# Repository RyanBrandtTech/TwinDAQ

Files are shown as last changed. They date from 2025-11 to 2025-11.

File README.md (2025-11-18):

# TwinDAQ
* An STM32-based two-channel analog I/O data acquisition system and development board

## Features
* Two analog inputs accessible with SMA connectors
* Two analog outputs accessible with SMA connectors
* Eight digital GPIO accessible via 0.1" female pin headers
* Two RGB LEDs for visual debugging
* Connector for SWD interfacing
* Connector for UART interfacing
* Micro-USB for 5V power and USB2.0 communications

### Dimensions and Images
40 mm x 60 mm
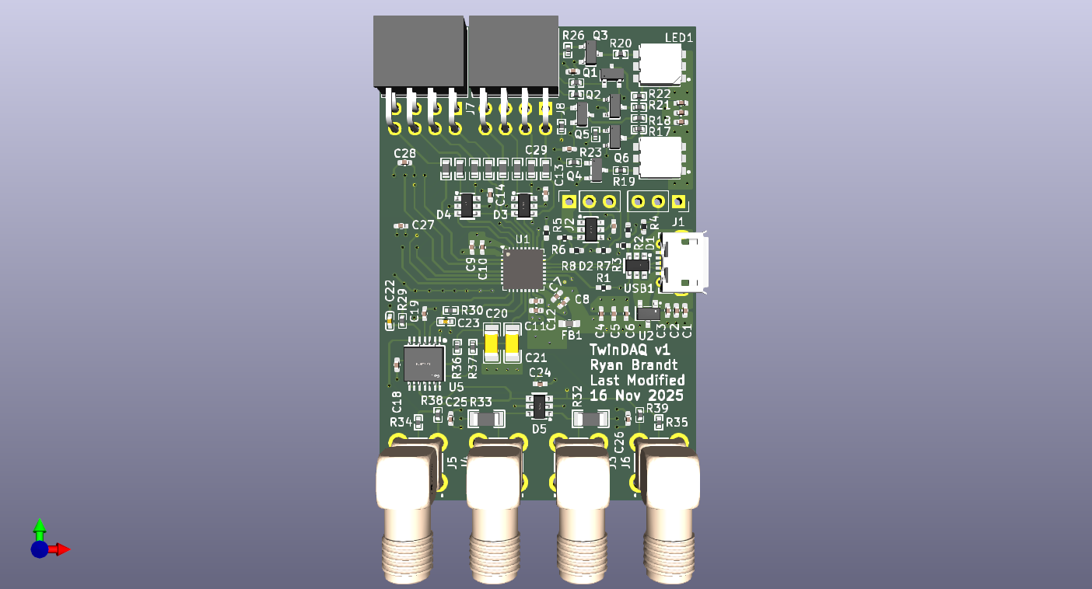
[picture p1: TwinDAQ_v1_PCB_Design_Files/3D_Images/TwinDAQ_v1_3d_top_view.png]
Top View of the TwinDAQv1 PCBA Top View

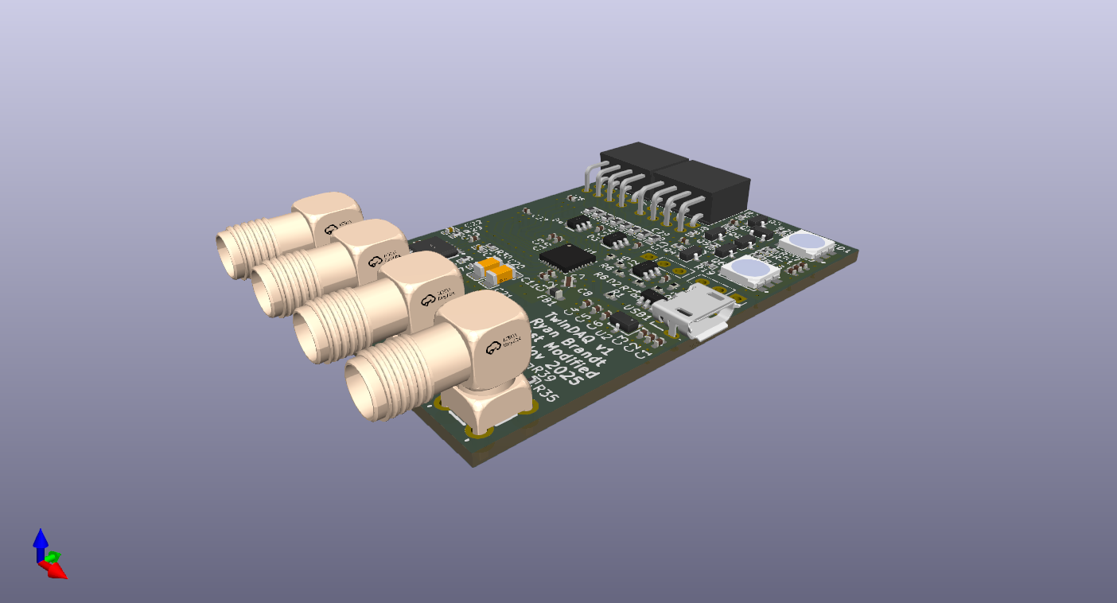
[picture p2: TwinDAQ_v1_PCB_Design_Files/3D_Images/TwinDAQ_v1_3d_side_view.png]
Front Side View of the TwinDAQv1 PCBA Front Side View

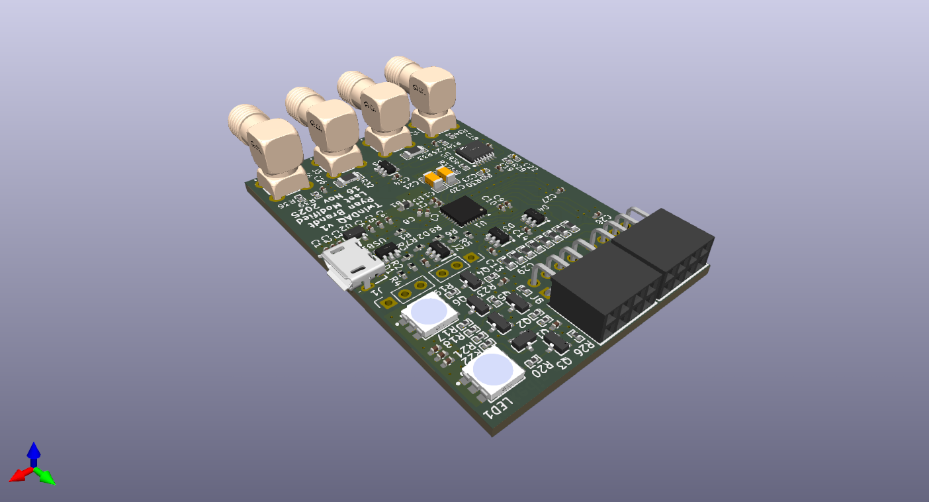
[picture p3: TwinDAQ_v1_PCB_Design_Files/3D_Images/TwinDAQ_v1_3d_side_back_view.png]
Back Side View of the TwinDAQv1 PCBA Back Side View

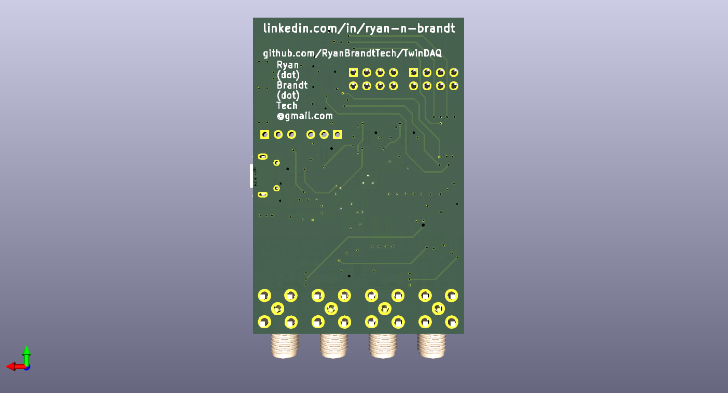
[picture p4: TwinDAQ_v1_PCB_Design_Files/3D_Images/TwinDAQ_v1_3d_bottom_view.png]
Bottom View of the TwinDAQv1 PCBA Bottom View


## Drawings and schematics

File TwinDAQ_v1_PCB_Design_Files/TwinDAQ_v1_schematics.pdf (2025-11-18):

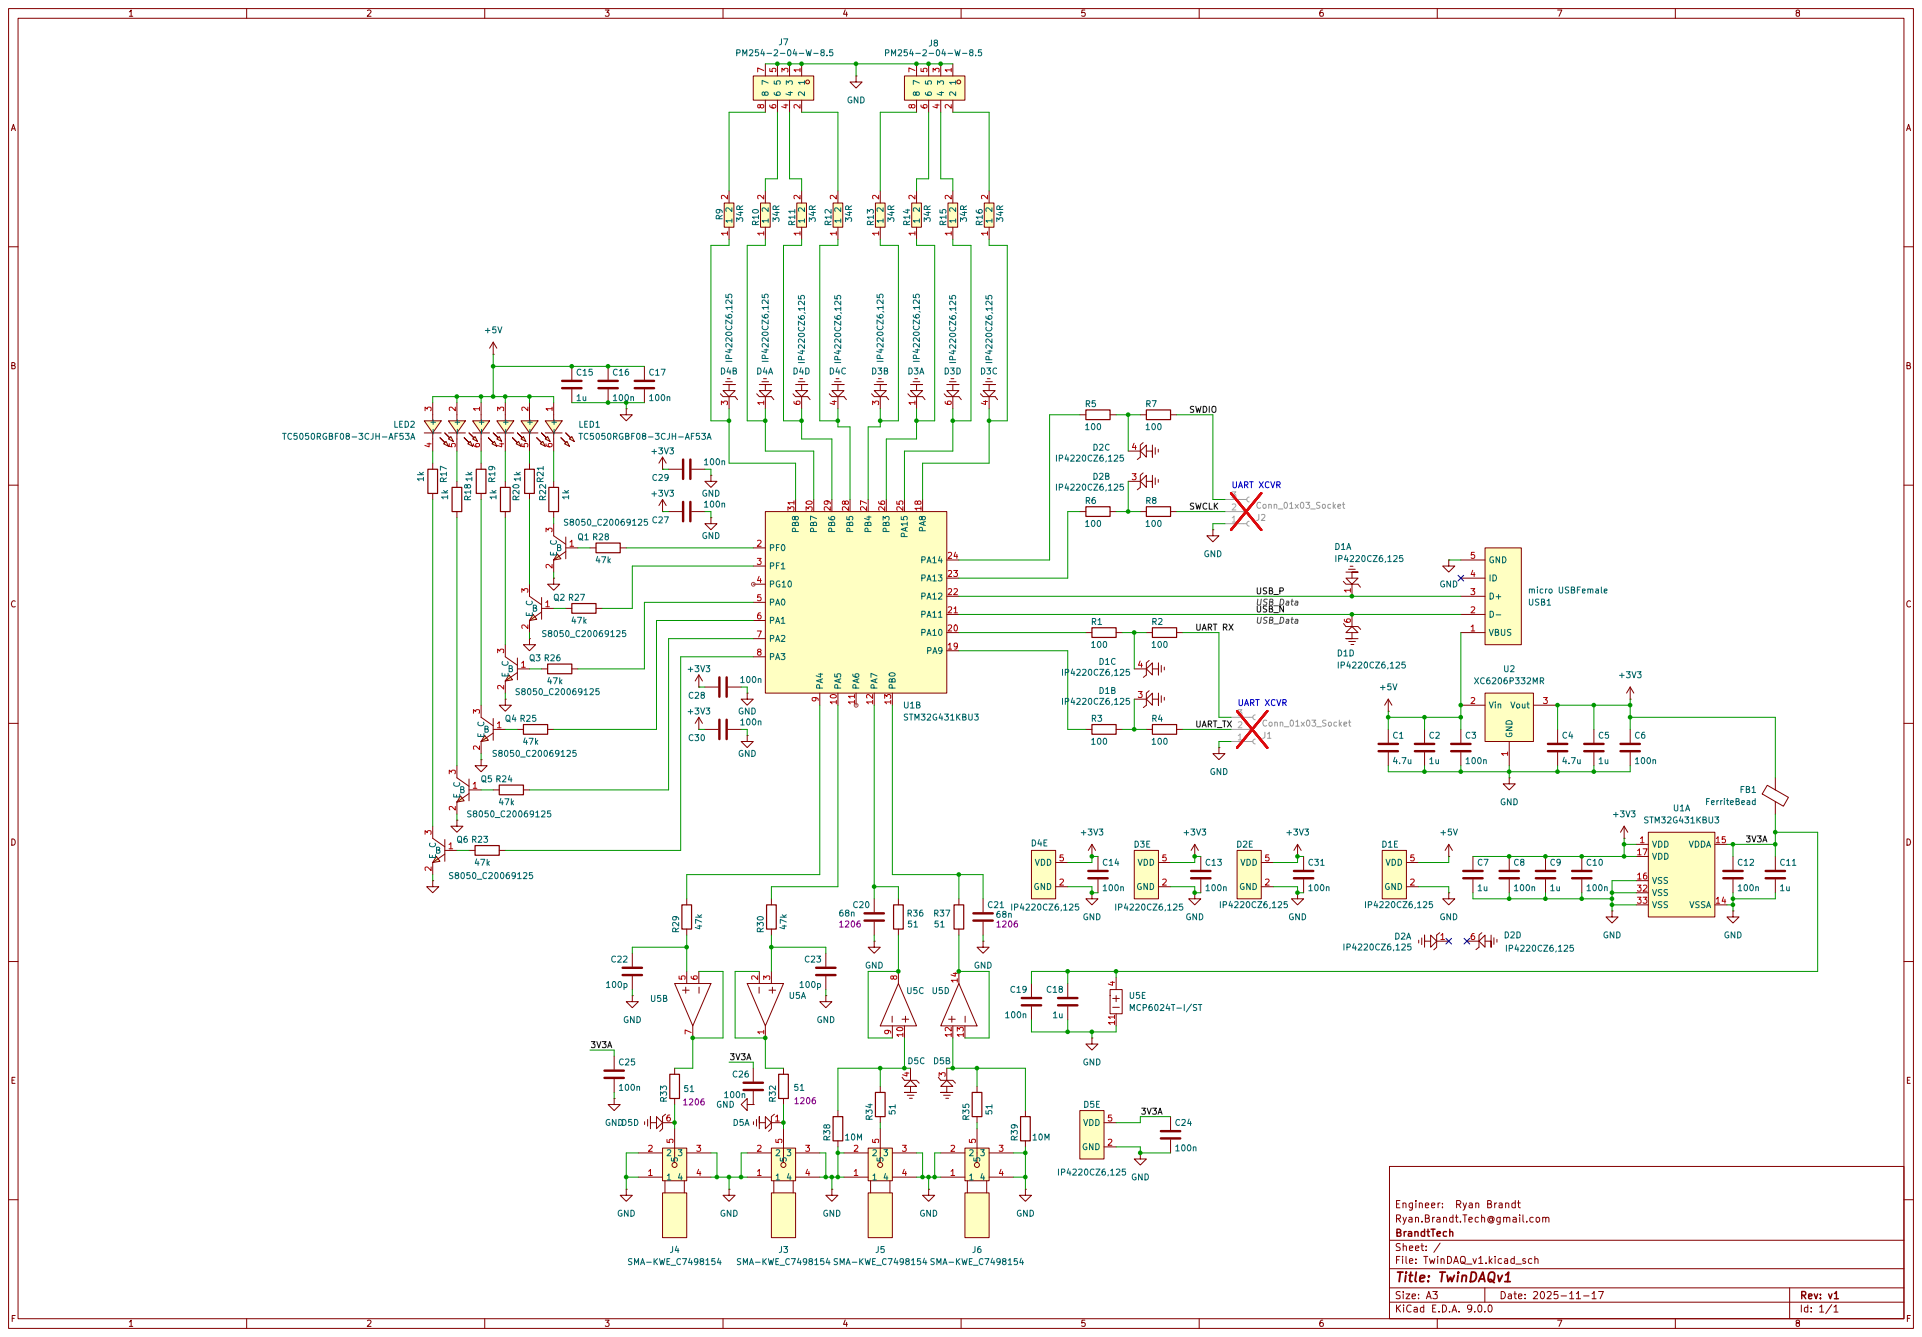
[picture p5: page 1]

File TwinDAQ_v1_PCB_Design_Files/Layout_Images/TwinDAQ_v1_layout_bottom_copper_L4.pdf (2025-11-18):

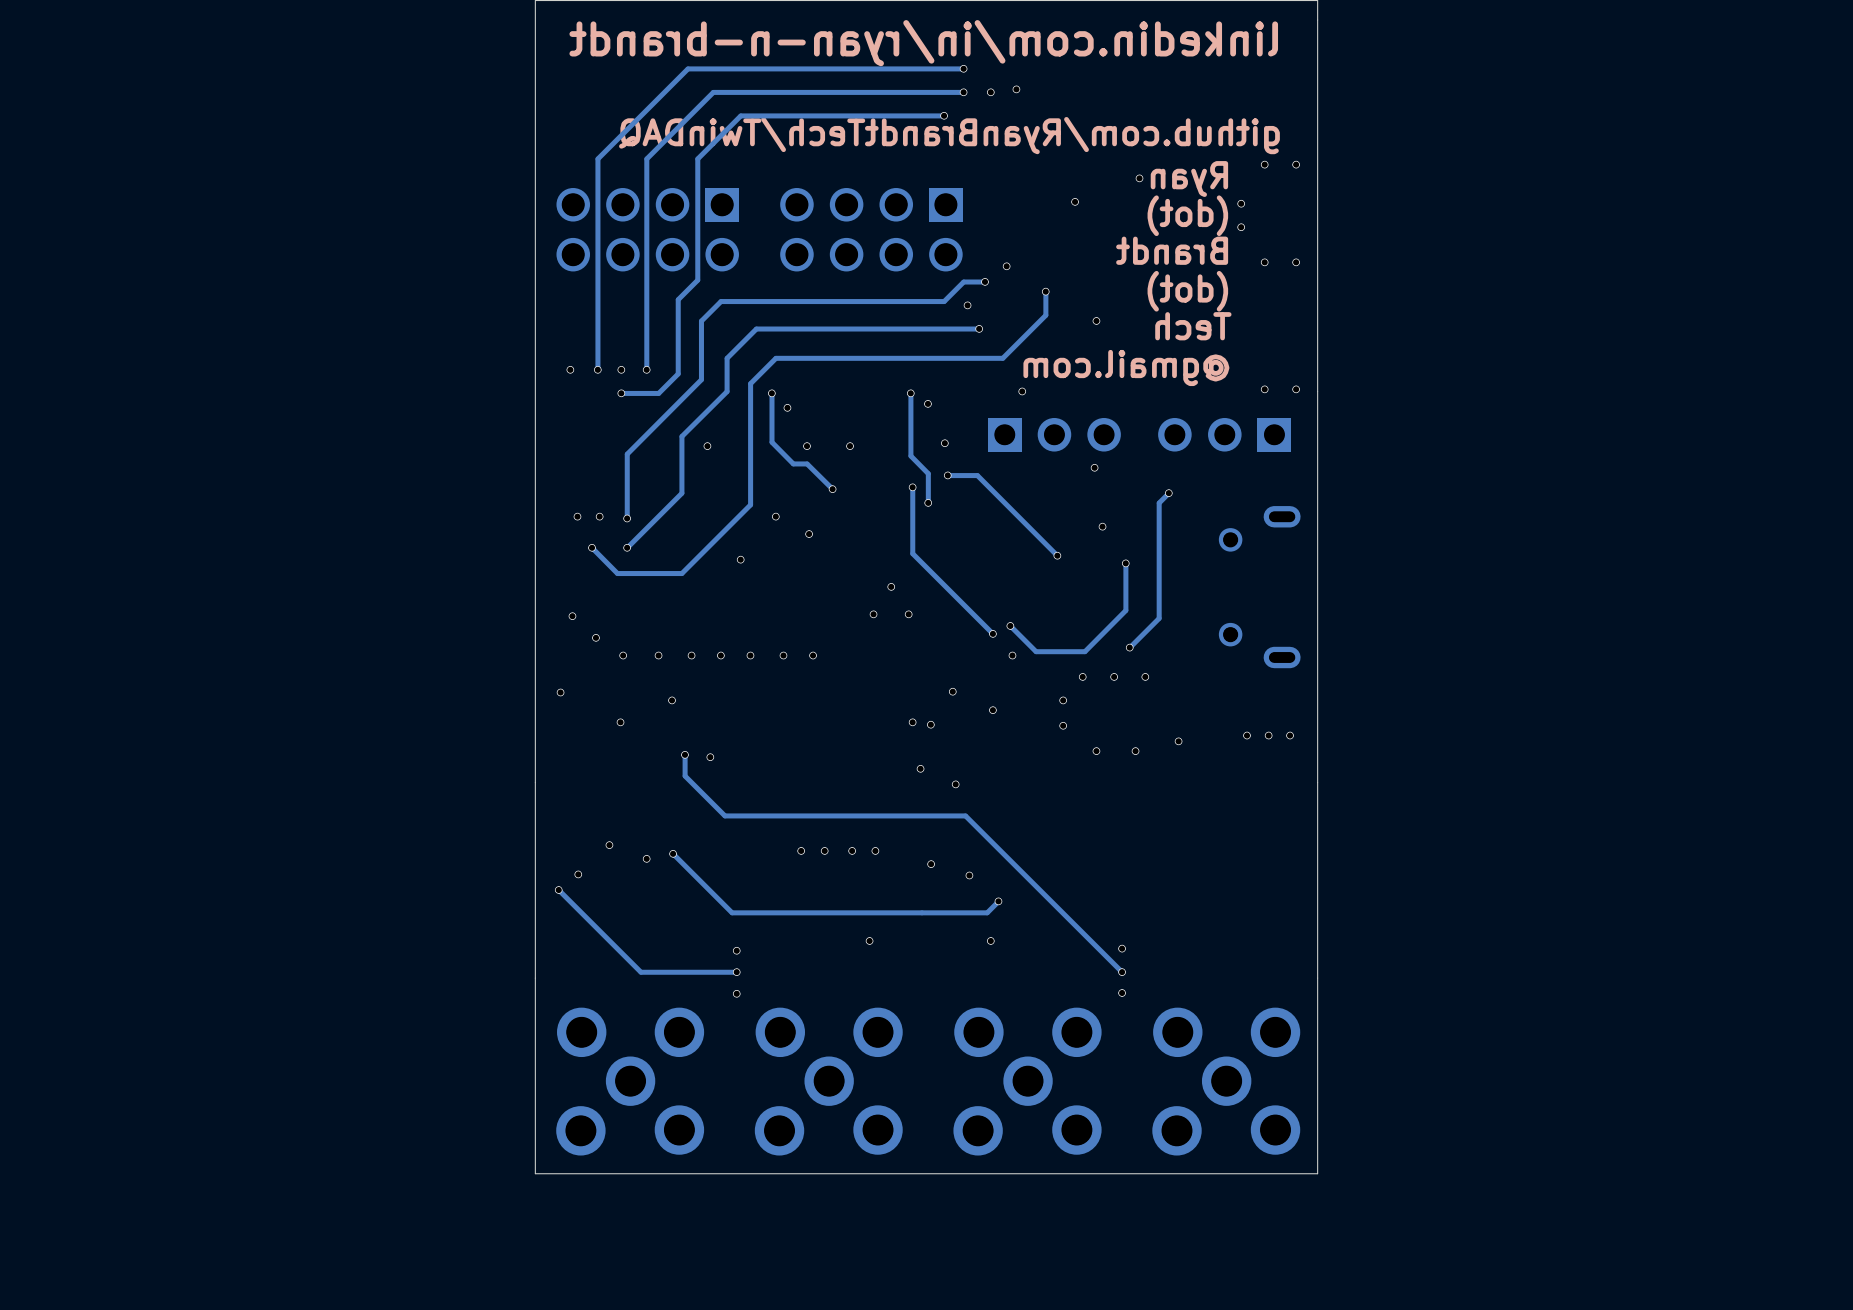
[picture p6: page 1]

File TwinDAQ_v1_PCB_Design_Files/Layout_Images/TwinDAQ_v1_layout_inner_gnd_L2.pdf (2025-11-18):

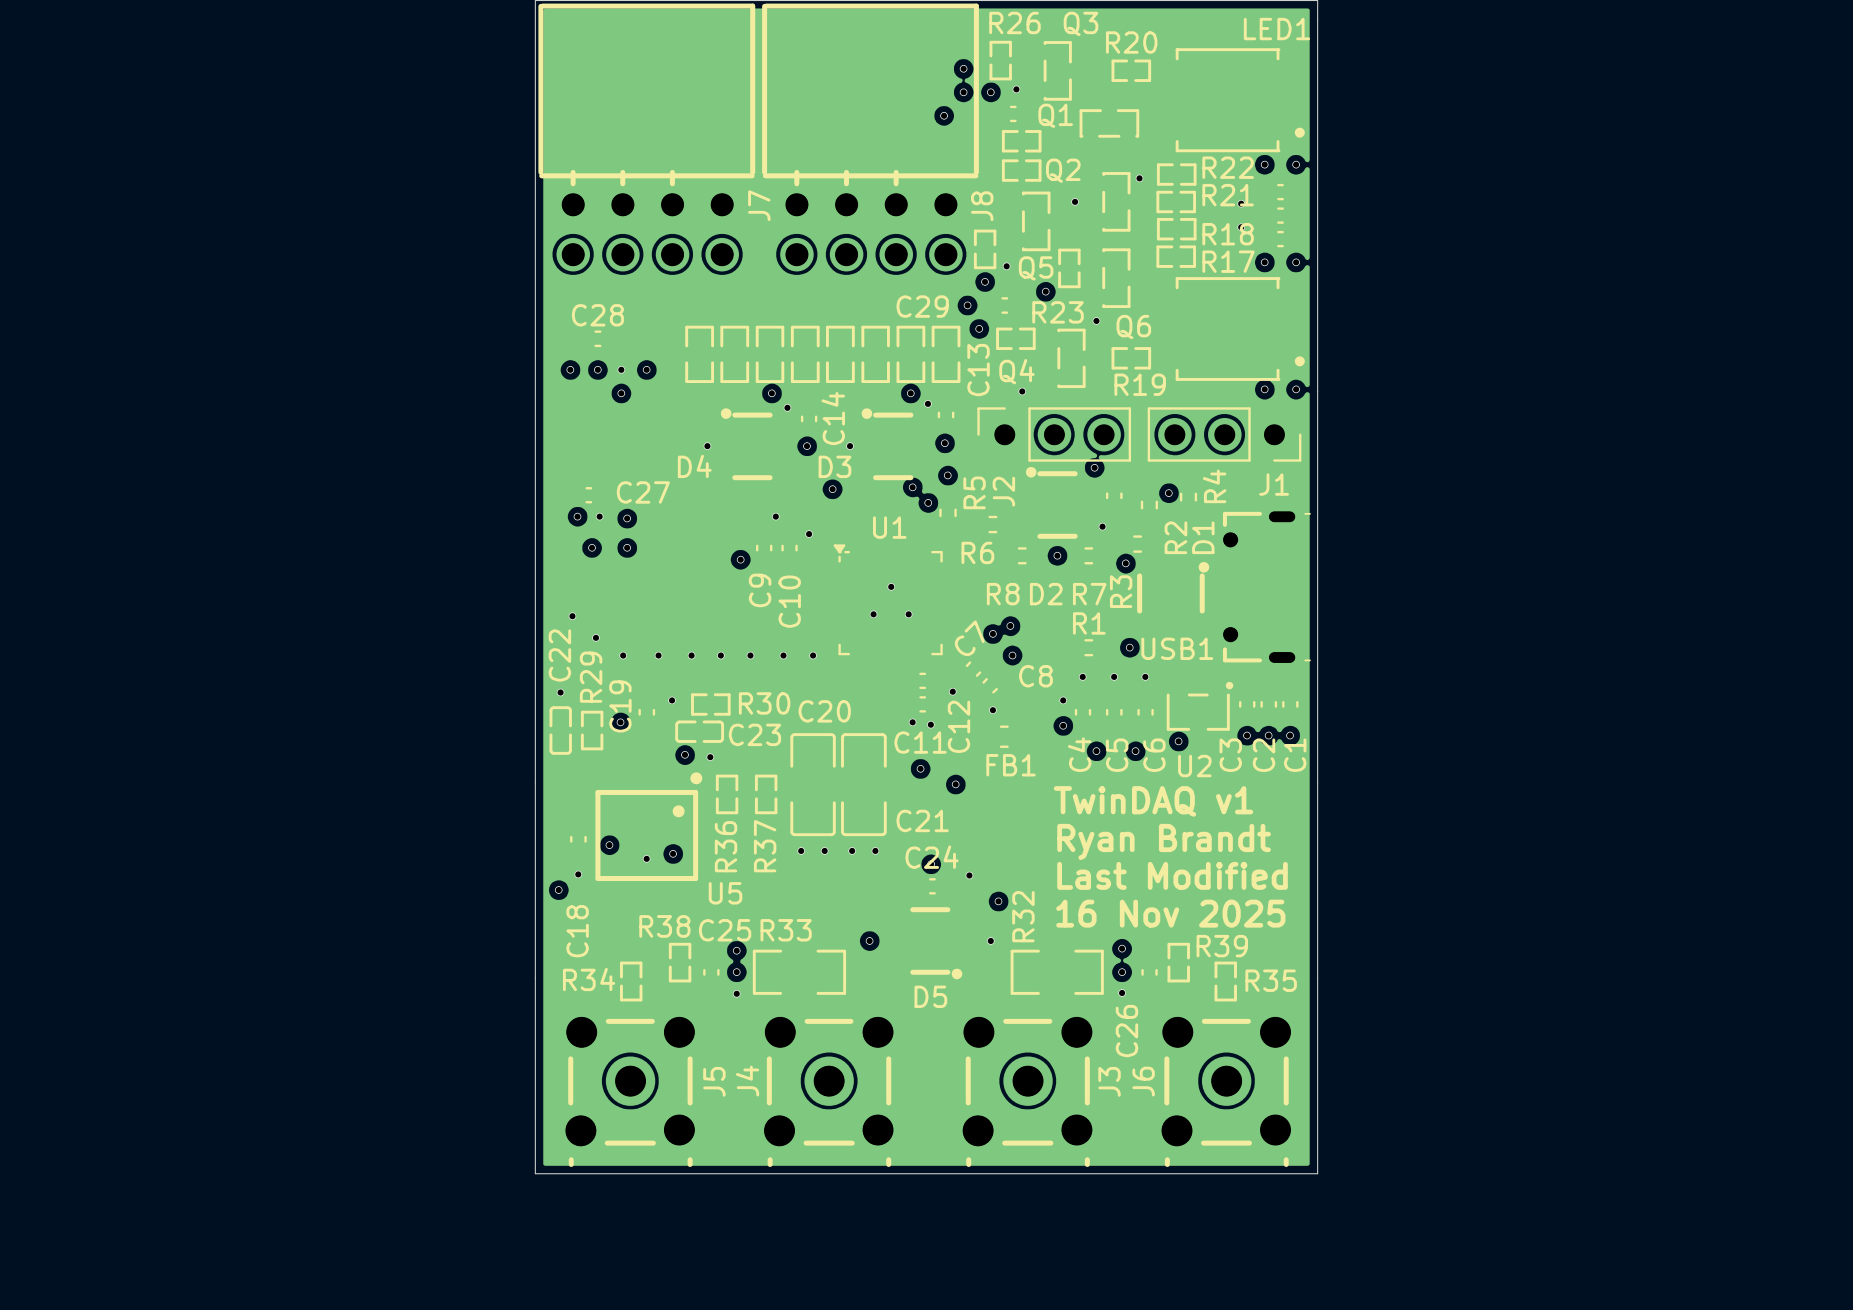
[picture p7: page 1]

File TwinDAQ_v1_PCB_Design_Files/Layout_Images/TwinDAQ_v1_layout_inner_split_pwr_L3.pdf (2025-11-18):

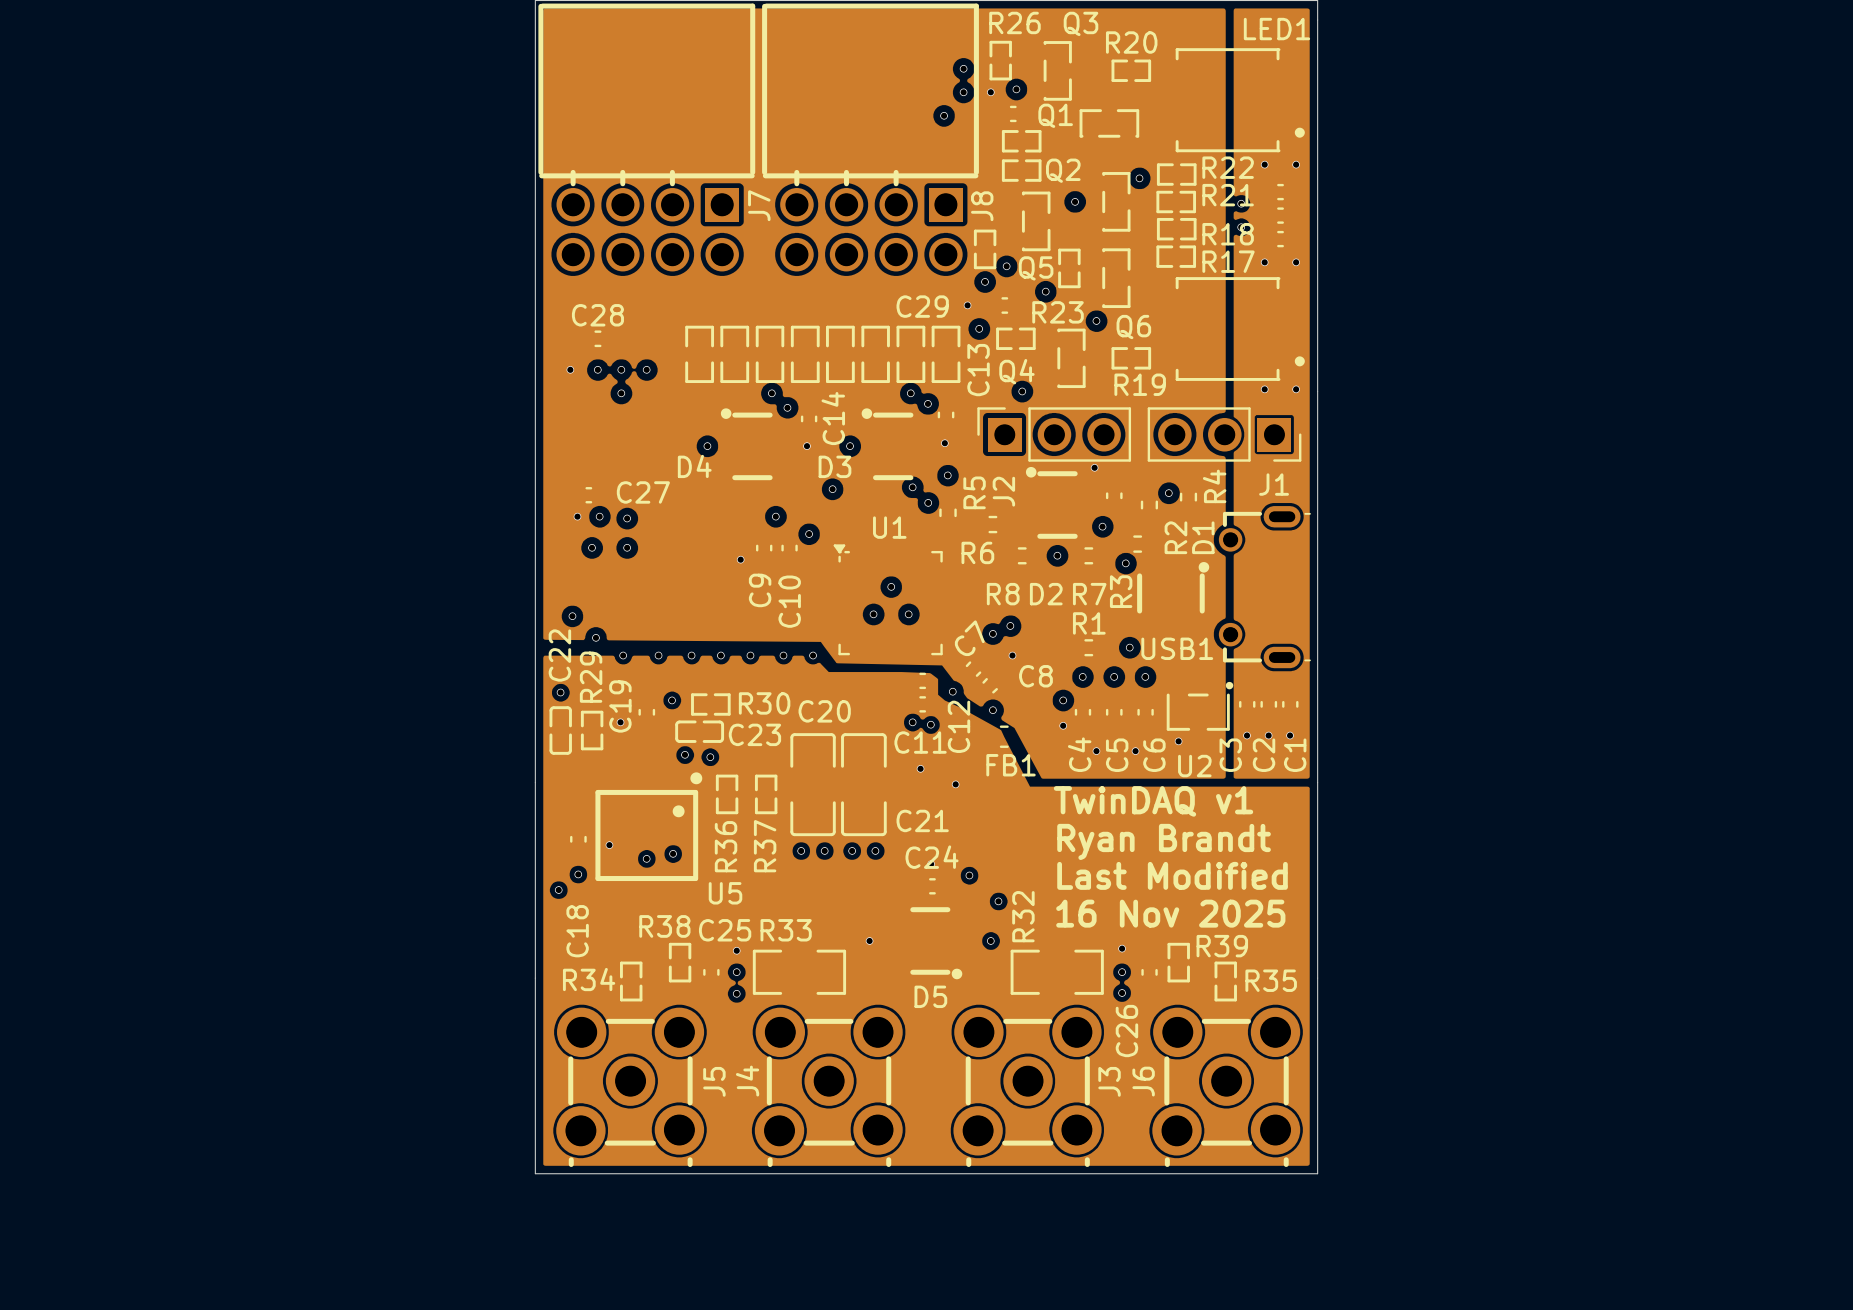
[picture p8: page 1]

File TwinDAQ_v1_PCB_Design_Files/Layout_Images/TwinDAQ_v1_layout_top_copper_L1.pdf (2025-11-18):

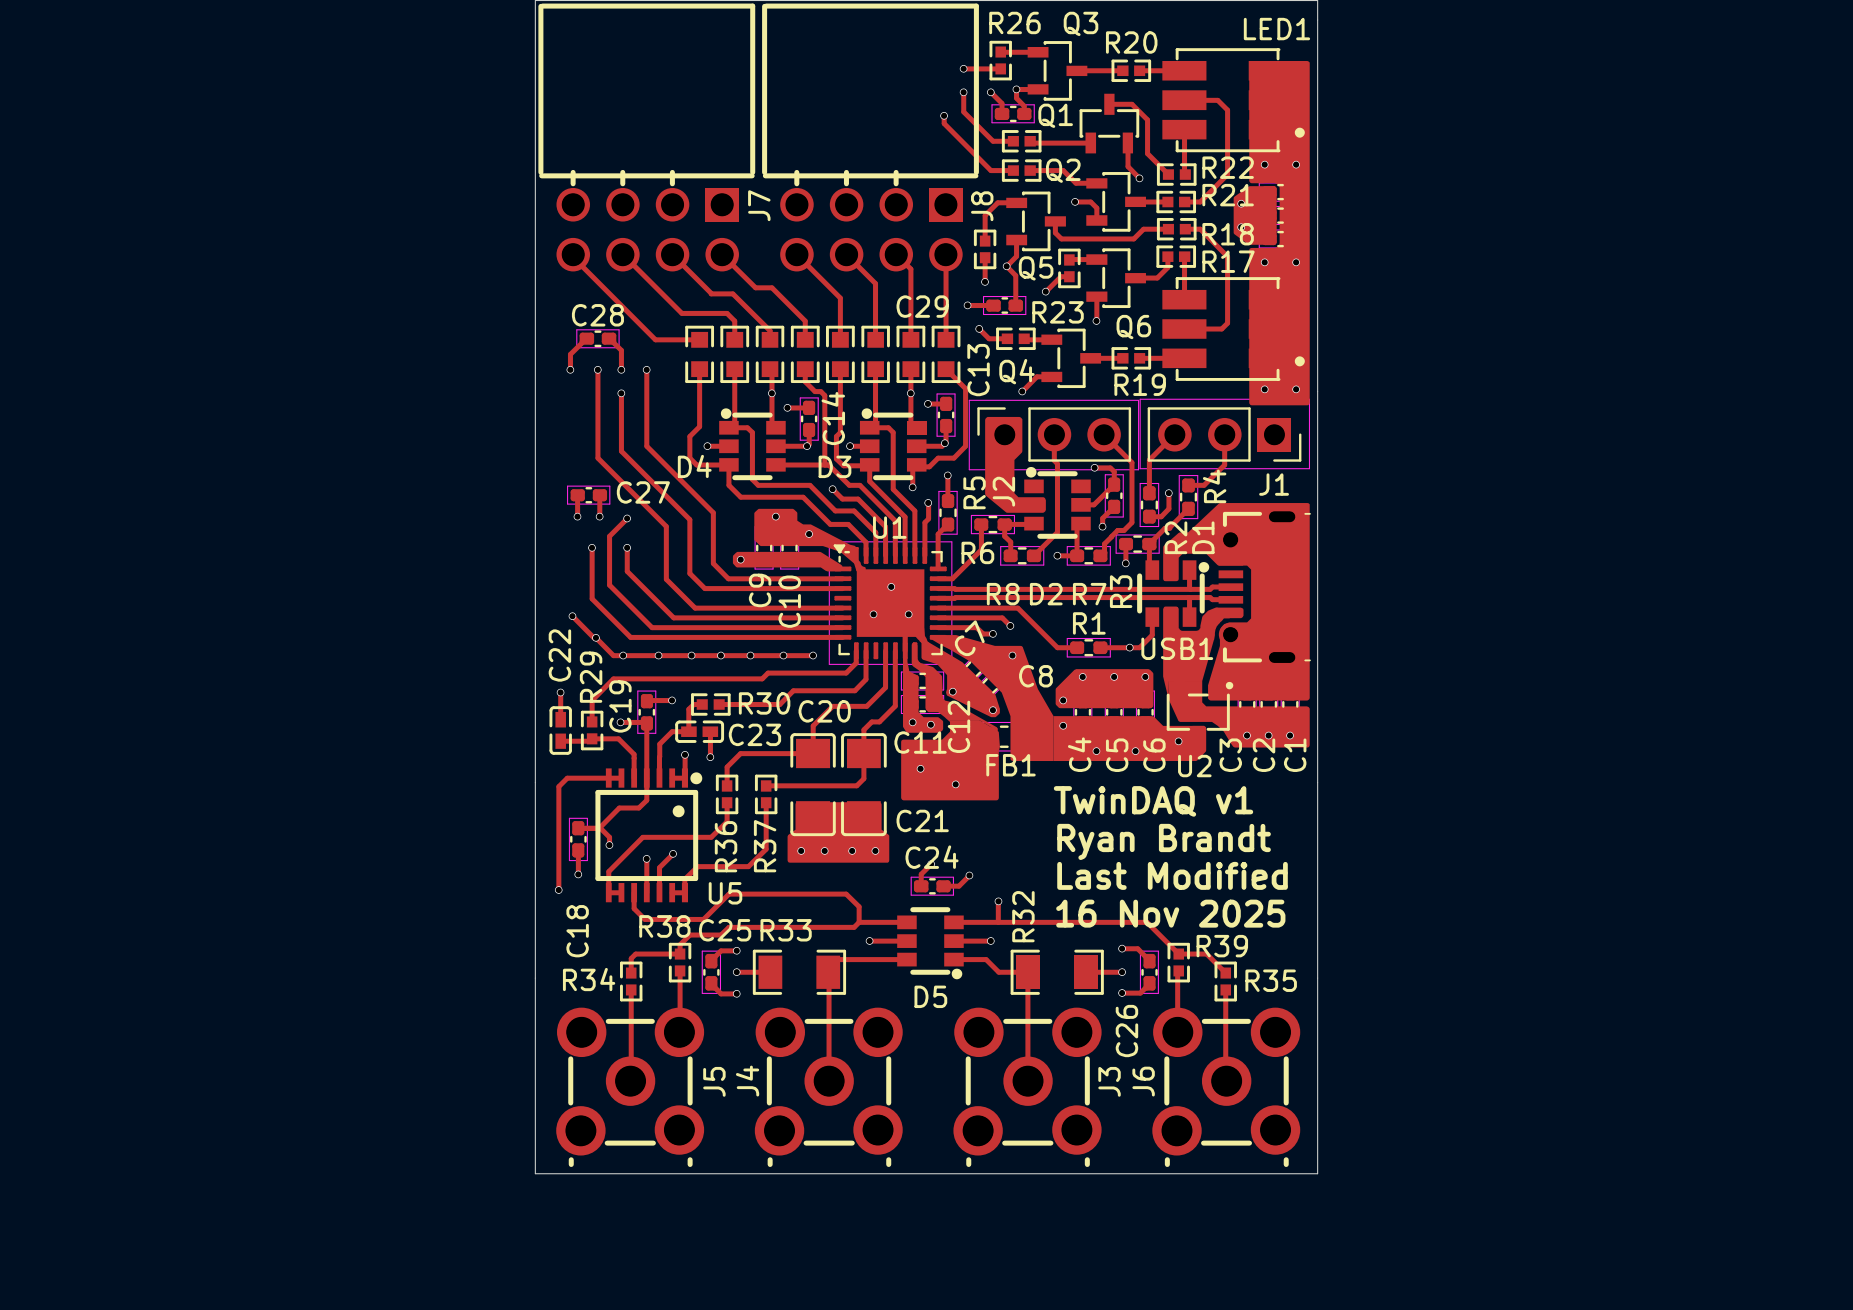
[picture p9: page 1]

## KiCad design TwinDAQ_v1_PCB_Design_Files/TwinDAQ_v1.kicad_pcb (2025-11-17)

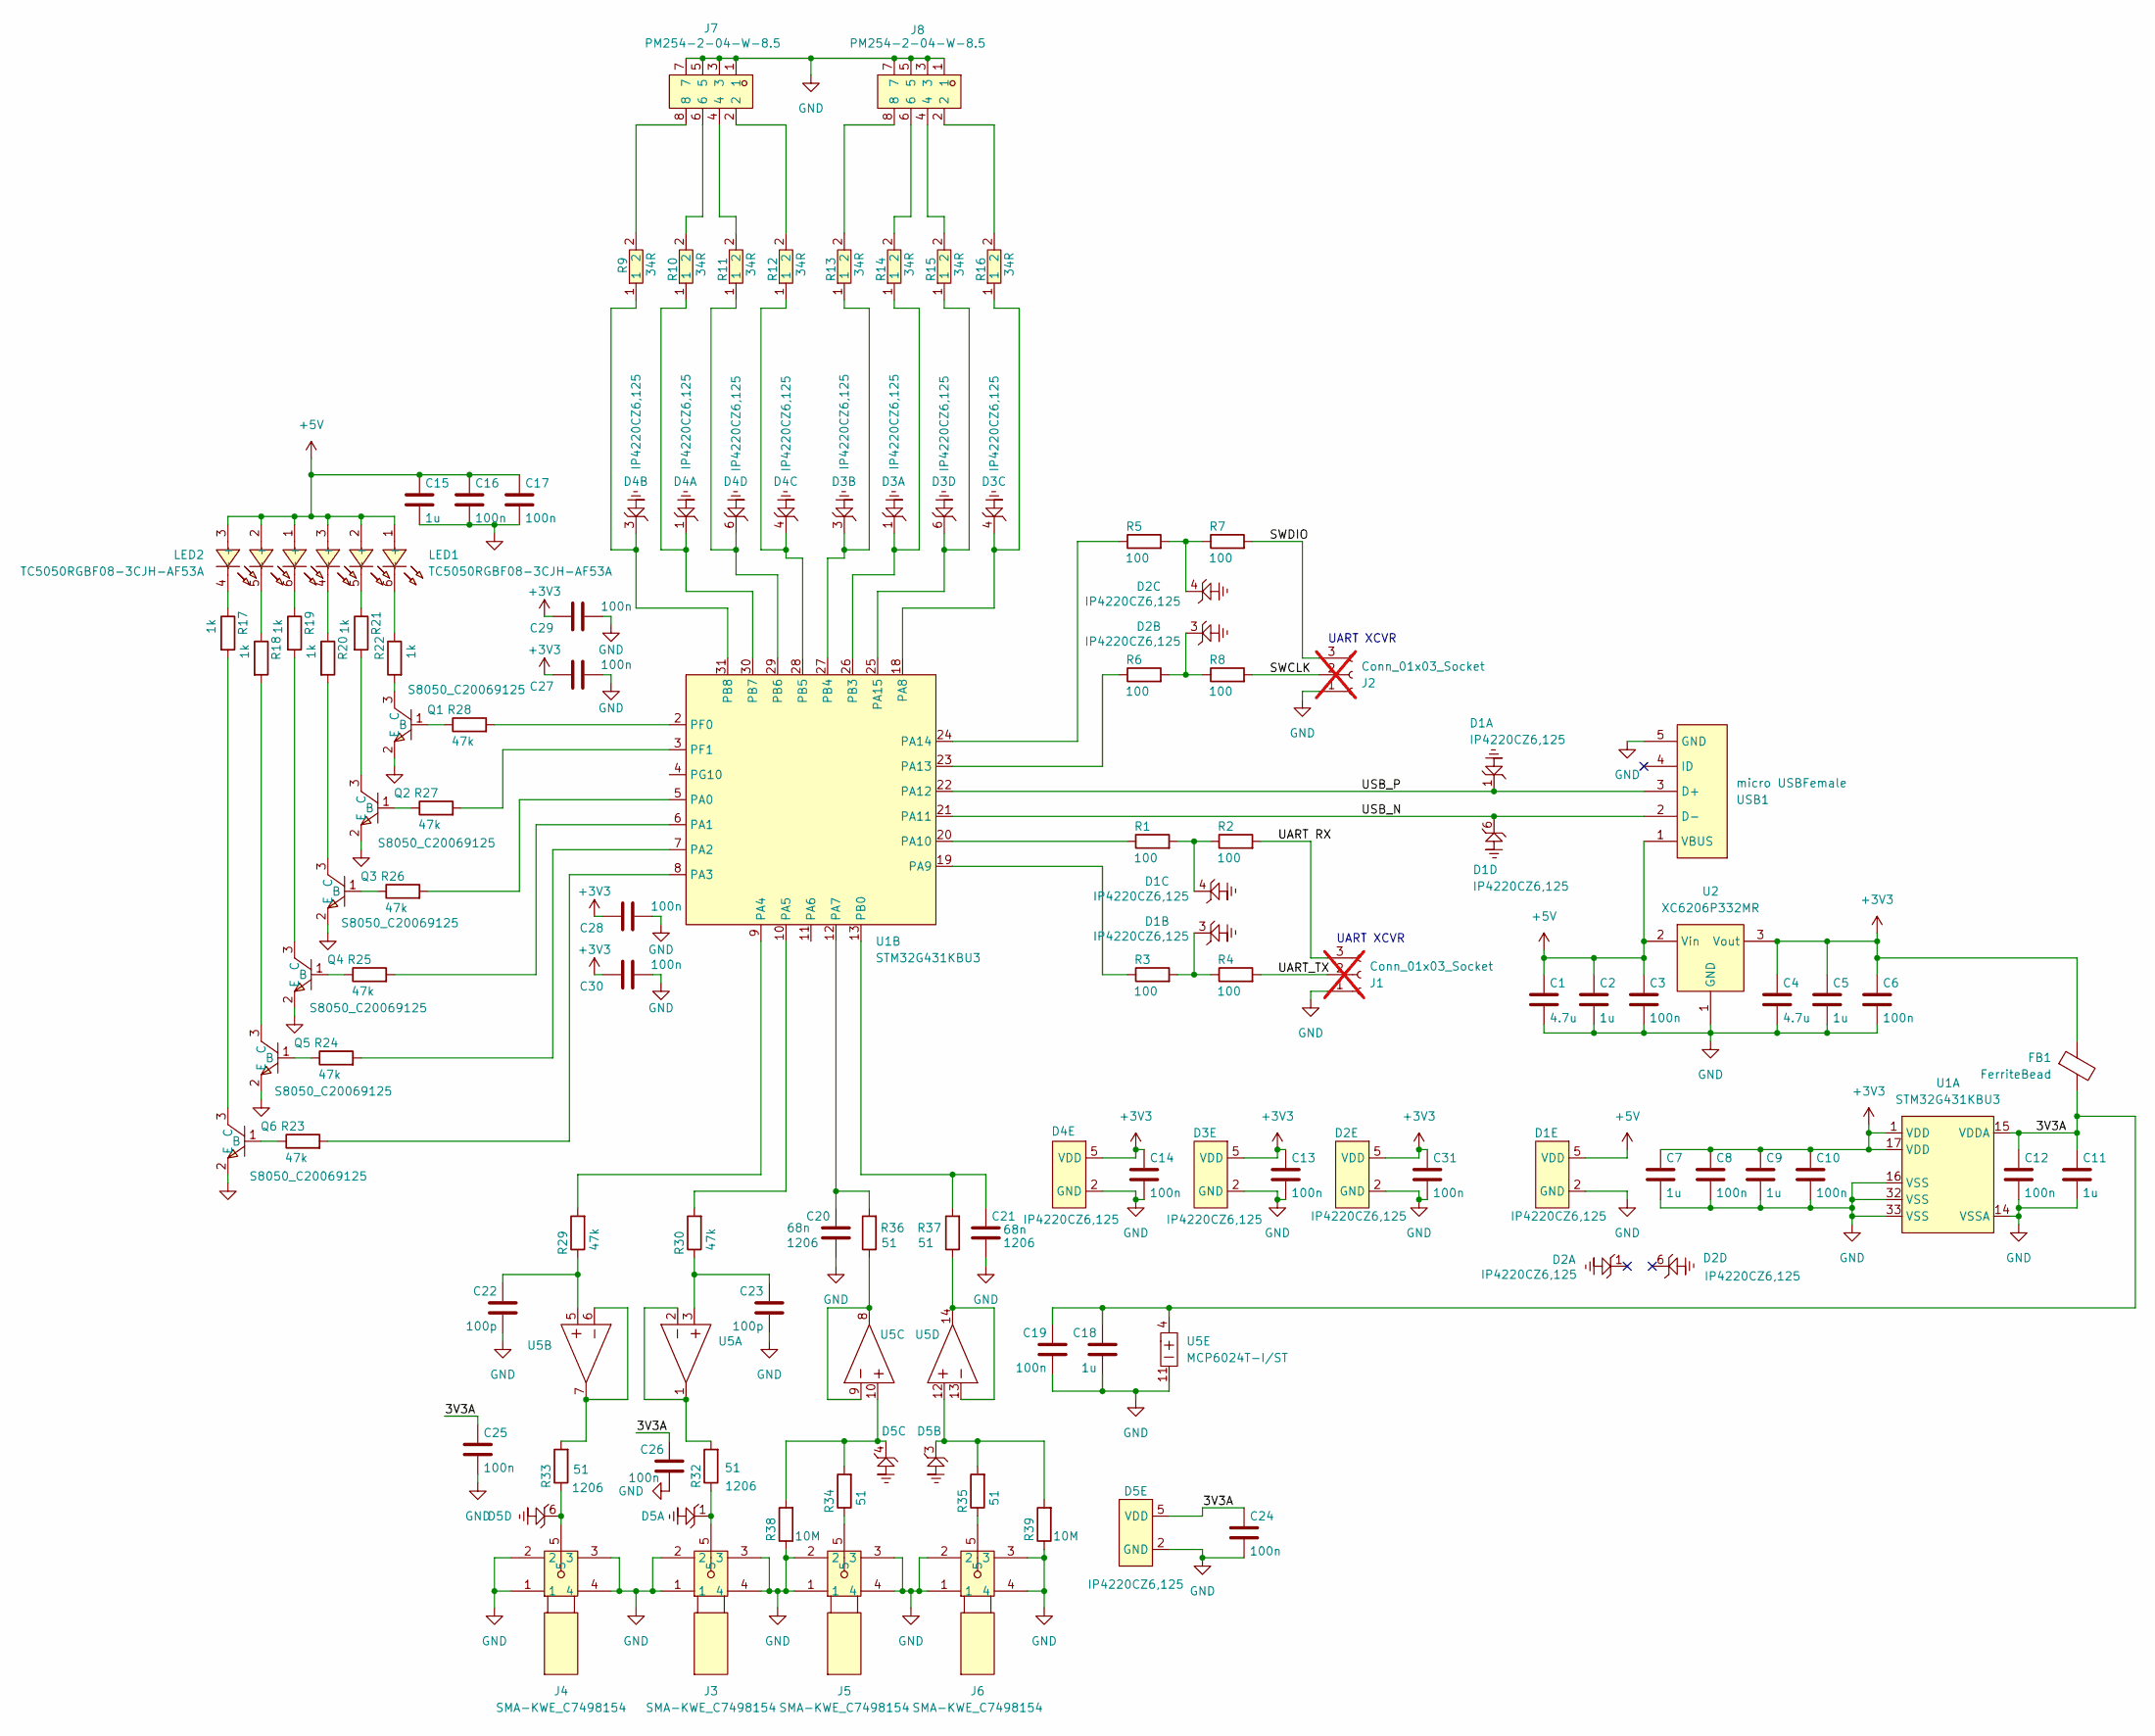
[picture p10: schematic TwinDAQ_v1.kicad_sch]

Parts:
C1, C4: 4.7u; C_0402_1005Metric_Pad0.74x0.62mm_HandSolder; LCSC Part C23733
C2, C5, C7, C9, C11, C15, C18: 1u; C_0402_1005Metric_Pad0.74x0.62mm_HandSolder; LCSC Part C14445
C3, C6, C8, C10, C12, C13, C14, C16, C17, C19, C24, C25, C26, C27, C28, C29, C30, C31: 100n; C_0402_1005Metric_Pad0.74x0.62mm_HandSolder; LCSC Part C1525
C20, C21: 68n; C1206; LCSC Part C77084
C22, C23: 100p; C0402; LCSC Part C1546
D1, D2, D3, D4, D5: IP4220CZ6,125; TSOP-6_L3.0-W1.5-P0.95-LS2.8-BR; LCSC Part C282546
FB1: FerriteBead; L_0603_1608Metric_Pad1.05x0.95mm_HandSolder; LCSC Part C1002
J1, J2: Conn_01x03_Socket; PinSocket_1x03_P2.54mm_Vertical; LCSC Part C541850; not fitted
J3, J4, J5, J6: SMA-KWE_C7498154; SMA-TH_SMA-KWE_C7498154; LCSC Part C7498154
J7, J8: PM254-2-04-W-8.5; HDR-TH_8P-P2.54-H-F-R2-C4-W8.5; LCSC Part C2897424
LED1, LED2: TC5050RGBF08-3CJH-AF53A; LED-SMD_6P-L5.0-W5.0-TL_TC5050RGBF08; LCSC Part C784540
Q1, Q2, Q3, Q4, Q5, Q6: S8050_C20069125; SOT-23-3_L2.9-W1.3-P1.90-LS2.3-BR; LCSC Part C20069125
R1, R2, R3, R4, R5, R6, R7, R8: 100; R_0402_1005Metric_Pad0.72x0.64mm_HandSolder; LCSC Part C25076
R9, R10, R11, R12, R13, R14, R15, R16: 34R; R0603; LCSC Part C25193
R17, R18, R19, R20, R21, R22: 1k; R0402; LCSC Part C11702
R23, R24, R25, R26, R27, R28, R29, R30: 47k; R0402; LCSC Part C25792
R32, R33: 51; R1206; LCSC Part C18019
R34, R35, R36, R37: 51; R0402; LCSC Part C25125
R38, R39: 10M; R0402; LCSC Part C26082
U1: STM32G431KBU3; QFN-32-1EP_5x5mm_P0.5mm_EP3.45x3.45mm; LCSC Part C1341901
U2: XC6206P332MR; SOT-23-3_L2.9-W1.6-P1.90-LS2.8-BR; LCSC Part C5446
U5: MCP6024T-I/ST; TSSOP-14_L5.0-W4.4-P0.65-LS6.5-BL; LCSC Part C480630
USB1: micro USBFemale; MICRO-USB-SMD_5P-P0.65-H-F_C10418; LCSC Part C10418

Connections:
+3V3: C4.1, C5.1, C6.1, C7.1, C8.1, C9.1, C10.1, C13.1, C14.1, C27.1, C28.1, C29.1, C30.1, C31.1, D2.5 (VDD), D3.5 (VDD), D4.5 (VDD), FB1.1, U1.1 (VDD), U1.17 (VDD), U2.3 (Vout)
+5V: C1.1, C2.1, C3.1, C15.1, C16.1, C17.1, D1.5 (VDD), LED1.1 (+), LED1.2 (+), LED1.3 (+), LED2.1 (+), LED2.2 (+), LED2.3 (+), U2.2 (Vin), USB1.1 (VBUS)
/3V3A: C11.1, C12.1, C18.1, C19.1, C24.1, C25.1, C26.1, D5.5 (VDD), FB1.2, U1.15 (VDDA), U5.4
/SWCLK: J2.2, R8.2
/SWDIO: J2.3, R7.2
/UART RX: J1.3, R2.2
/UART_TX: J1.2, R4.2
/USB_N: D1.6, U1.21 (PA11), USB1.2 (D-)
/USB_P: D1.1, U1.22 (PA12), USB1.3 (D+)
GND: C1.2, C2.2, C3.2, C4.2, C5.2, C6.2, C7.2, C8.2, C9.2, C10.2, C11.2, C12.2, C13.2, C14.2, C15.2, C16.2, C17.2, C18.2, C19.2, C20.2, C21.2, C22.2, C23.2, C24.2, C25.2, C26.2, C27.2, C28.2, C29.2, C30.2, C31.2, D1.2 (GND), D2.2 (GND), D3.2 (GND), D4.2 (GND), D5.2 (GND), J1.1, J2.1, J3.1, J3.2, J3.3, J3.4, J4.1, J4.2, J4.3, J4.4, J5.1, J5.2, J5.3, J5.4, J6.1, J6.2, J6.3, J6.4, J7.1, J7.3, J7.5, J7.7, J8.1, J8.3, J8.5, J8.7, Q1.2 (E), Q2.2 (E), Q3.2 (E), Q4.2 (E), Q5.2 (E), Q6.2 (E), R38.1, R39.1, U1.14 (VSSA), U1.16 (VSS), U1.32 (VSS), U1.33 (VSS), U2.1 (GND), U5.11, USB1.5 (GND)
unnamed: C22.1, R29.1, U5.5
unnamed: C23.1, R30.1, U5.3
unnamed: D1.3, R3.2, R4.1
unnamed: D1.4, R1.2, R2.1
unnamed: D2.3, R6.2, R8.1
unnamed: D2.4, R5.2, R7.1
unnamed: D3.1, R14.1, U1.26 (PB3)
unnamed: D3.3, R13.1, U1.27 (PB4)
unnamed: D3.4, R16.1, U1.18 (PA8)
unnamed: D3.6, R15.1, U1.25 (PA15)
unnamed: D4.1, R10.1, U1.30 (PB7)
unnamed: D4.3, R9.1, U1.31 (PB8)
unnamed: D4.4, R12.1, U1.28 (PB5)
unnamed: D4.6, R11.1, U1.29 (PB6)
unnamed: D5.1, J3.5, R32.1
unnamed: D5.3, R35.2, R39.2, U5.12
unnamed: D5.4, R34.2, R38.2, U5.10
unnamed: D5.6, J4.5, R33.1
unnamed: J5.5, R34.1
unnamed: J6.5, R35.1
unnamed: J7.2, R12.2
unnamed: J7.4, R11.2
unnamed: J7.6, R10.2
unnamed: J7.8, R9.2
unnamed: J8.2, R16.2
unnamed: J8.4, R15.2
unnamed: J8.6, R14.2
unnamed: J8.8, R13.2
unnamed: LED1.4 (-), R20.1
unnamed: LED1.5 (-), R21.1
unnamed: LED1.6 (-), R22.1
unnamed: LED2.4 (-), R17.1
unnamed: LED2.5 (-), R18.1
unnamed: LED2.6 (-), R19.1
unnamed: Q1.1 (B), R28.1
unnamed: Q1.3 (C), R22.2
unnamed: Q2.1 (B), R27.1
unnamed: Q2.3 (C), R21.2
unnamed: Q3.1 (B), R26.1
unnamed: Q3.3 (C), R20.2
unnamed: Q4.1 (B), R25.1
unnamed: Q4.3 (C), R19.2
unnamed: Q5.1 (B), R24.1
unnamed: Q5.3 (C), R18.2
unnamed: Q6.1 (B), R23.1
unnamed: Q6.3 (C), R17.2
unnamed: R32.2, U5.1, U5.2
unnamed: R33.2, U5.6, U5.7
unnamed: R36.1, U5.8, U5.9
unnamed: R37.1, U5.13, U5.14
unnamed: R26.2, U1.5 (PA0)
unnamed: R25.2, U1.6 (PA1)
unnamed: R24.2, U1.7 (PA2)
unnamed: R23.2, U1.8 (PA3)
unnamed: R29.2, U1.9 (PA4)
unnamed: R30.2, U1.10 (PA5)
unnamed: C20.1, R36.2, U1.12 (PA7)
unnamed: R3.1, U1.19 (PA9)
unnamed: R1.1, U1.20 (PA10)
unnamed: R6.1, U1.23 (PA13)
unnamed: R5.1, U1.24 (PA14)
unnamed: C21.1, R37.2, U1.13 (PB0)
unnamed: R28.2, U1.2 (PF0)
unnamed: R27.2, U1.3 (PF1)

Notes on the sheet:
UART XCVR

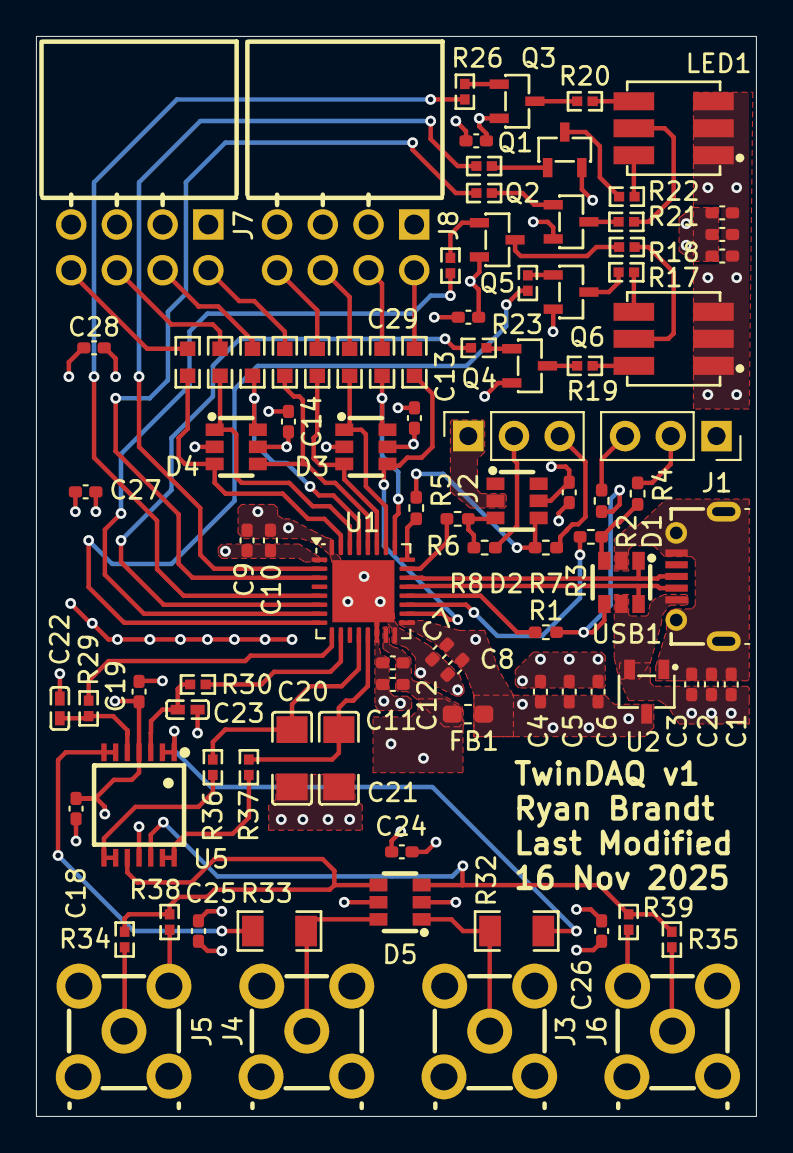
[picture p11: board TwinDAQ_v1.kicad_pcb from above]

Board: 4 copper layers, 40.0 x 60.0 mm, 95 parts (0 on the bottom side), 74 nets.

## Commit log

2025-11-17 Add PCB Design Files for v1 Order
    [TwinDAQ_v1.kicad_pcb, TwinDAQ_v1.kicad_sch]
2025-11-18 Add Images of PCB Design for Documentation
